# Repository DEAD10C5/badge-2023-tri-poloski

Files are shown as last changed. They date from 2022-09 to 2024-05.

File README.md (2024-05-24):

# взаимоблокировщики - гопник badge - Путин хуйло

 

## Created by

Будущее подпольной кибер-безопасности

- Concept: Yaya Pancho
- Translations: @muscovitebob
- Puzzle: [Hermit](mailto:hermit@dead10c5.org)
- Hardware: [p0lr](mailto:p0lr@dead10c5.org) [@thedevilsvoice](mailto:thedevilsvoice@dead10c5.org)
- Software: [p0lr](mailto:p0lr@dead10c5.org) [@thedevilsvoice](mailto:thedevilsvoice@dead10c5.org)

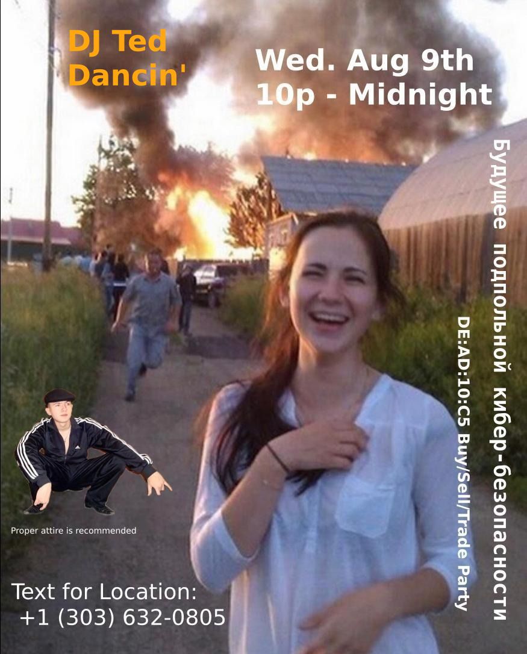
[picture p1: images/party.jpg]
party


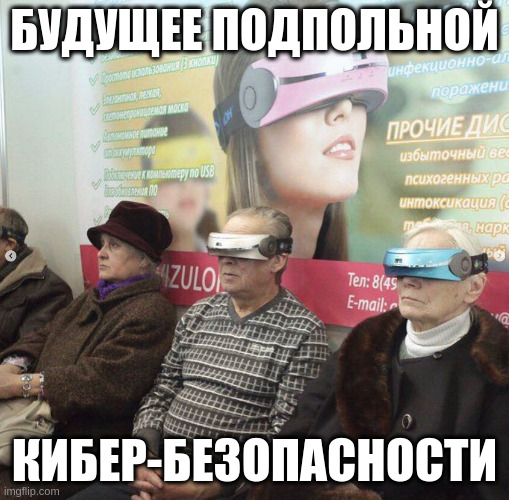
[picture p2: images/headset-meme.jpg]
headset
)

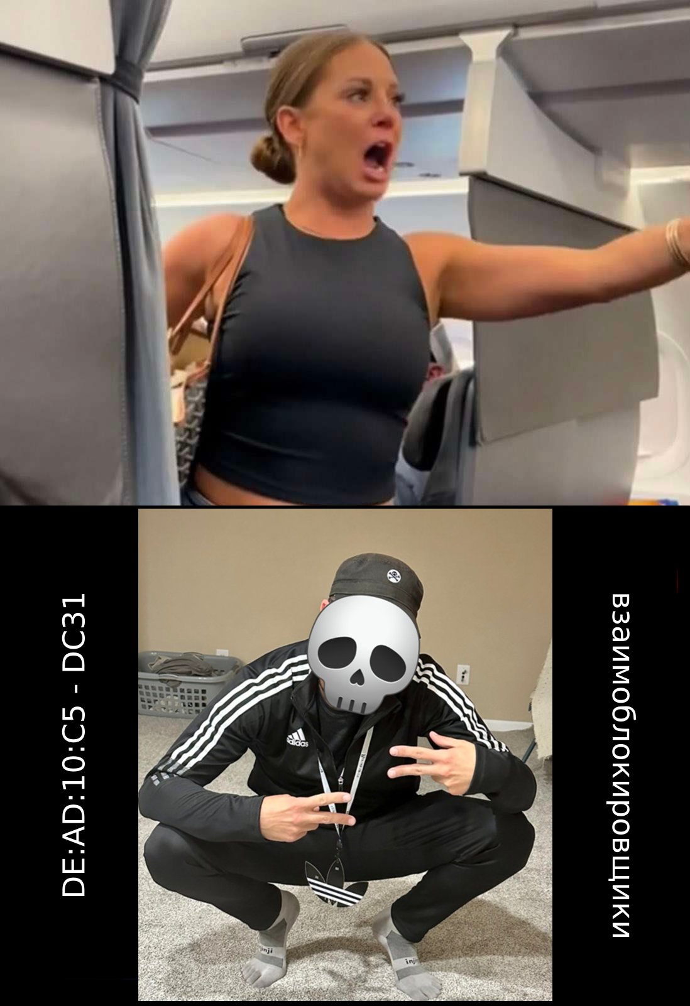
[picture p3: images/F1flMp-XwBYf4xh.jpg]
airplane


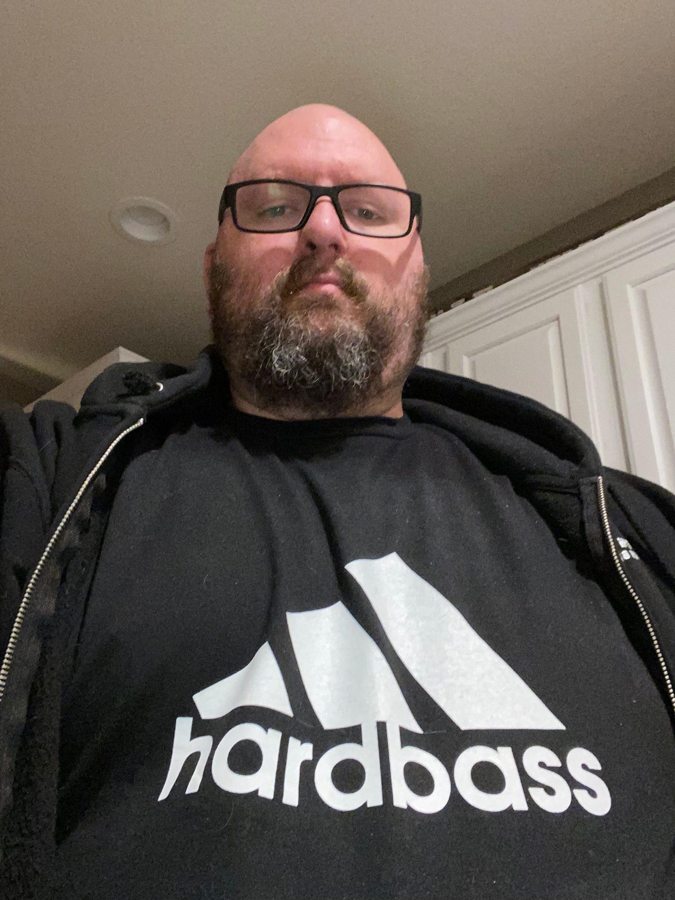
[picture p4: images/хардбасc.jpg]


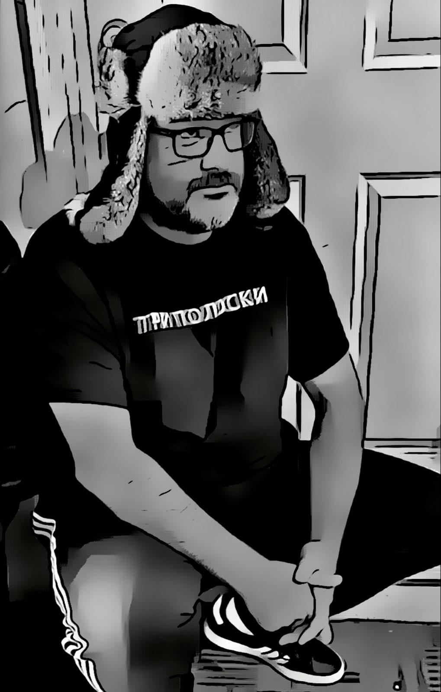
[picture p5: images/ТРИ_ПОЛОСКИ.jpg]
ТРИ-ПОЛОСКИ


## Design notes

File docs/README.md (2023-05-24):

# Docs go here

Generate the Gerbers like so:
`bash kicad-exports -c docs/gerbers.kibot.yaml -d docs -b kicad/adidas.kicad_pcb -e kicad/adidas.kicad_sch`

## Routing

1. From the main KiCAD window, select the "Plugin and Contect Manager"
2. Install the "Freerouting" plug in.
3. Install the "PCBWay plug in for KiCAD"

You can also use the older [FreeRouting](https://github.com/freerouting/freerouting) tool.

```sh
locate freeRouting.jar
java -jar /opt/layout/bin/freeRouting.jar
```

Board Settings

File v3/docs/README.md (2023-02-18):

# Docs go here

Generate the Gerbers like so:
`bash kicad-exports -c docs/gerbers.kibot.yaml -d docs -b kicad/adidas.kicad_pcb -e kicad/adidas.kicad_sch`

## Routing

[FreeRouting](https://github.com/freerouting/freerouting)

## Setup

- Install Arduino IDE.
- Click `file -> Preferences`
- Add this to `Additional Boards manager URLS`: `http://drazzy.com/package_drazzy.com_index.json`
- Click `ok`
- Click on `Tools -> Boards Manager` and make sure `ATTinyCore` is installed.
  - Install version 1.5.2 or later.
- Select one of the ATTiny 441/841 board types.

## Libraries

- [ATTinyCore Universal](https://github.com/SpenceKonde/ATTinyCore)
- [TinyMPU6050](https://github.com/gabriel-milan/TinyMPU6050)

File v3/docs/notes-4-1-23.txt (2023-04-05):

1. move the MPU or the battery so it is easier to insert the coin cell
2. The mounting hole is missing from the board. (1, 2, or 3 holes?)
3. Can the chip be programmed while it is attached to the board? Depends on connections?
4. the switch is not needed with "regular" LED. Could still be used for blink patterns?
5. Break out all the pins from the chip from now on. That way you can still prototype
   if there is some issue with the circuits. 

we can use the "optiboot" core and program the chip using USB to serial converter. 

## Burn Bootloader

- Use ARduino IDE 2.0.4 or later
- Add the "Arduino AVR Boards" from board manager.
- Upload the `src/ArduinoISP` sketch to the Arduino UNO.
- Connect board and "get board info", you should see serial number.

Pin details for ISP header:
// By default, the hardware SPI pins MISO, MOSI and SCK are used to communicate
// with the target. On all Arduinos, these pins can be found
// on the ICSP/SPI header:
//
//               MISO °. . 5V (!) Avoid this pin on Due, Zero...
//               SCK   . . MOSI
//                     . . GND
//
// On some Arduinos (Uno,...), pins MOSI, MISO and SCK are the same pins as
// digital pin 11, 12 and 13, respectively. That is why many tutorials instruct
// you to hook up the target to these pins. If you find this wiring more
// practical, have a define USE_OLD_STYLE_WIRING. This will work even when not
// using an Uno. (On an Uno this is not needed).

Choose Bootloader UART1 if you are using ISP header programming since the TX is on pin 8 and the RX is on pin 9.

const uint8_t  DATA_PIN   = PA5; // pin 8
const uint8_t  CLOCK_PIN  = PA4; // SCL pin 9

Choose board ATtiny441/841 with Optiboot. This allows programming via USB to Serial cable not just ISP header.
Programmer: ATtiny as ISP (ATtiny Core)

For USB to TTL, while viewing the BACK of the board:
- Green/Grey wire: TX out of the USB port, RX on the chip, connect to bottom center pin on ISP header next to green/grey.
- White wire: RX into USB port, TX on the chip, connect bottom left (below power).
- Black wire: Connect to negative (-) port on back, top right of ISP header.
- Red/Orange wire: Connect to (+) port on the back, top l;eft of ISP header.

Connect board, burn bootloader from board menu.
Then you can start uploading sketches

## Programming

Once you burn the bootloader to the chip, you can reflash many times using the easy USB to TTL cable.

[Add the ATTINY 841 using these directions](https://github.com/SpenceKonde/ATTinyCore/blob/v2.0.0-devThis-is-the-head-submit-PRs-against-this/Installation.md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)

[SparkFun FT231X Breakout](https://www.sparkfun.com/products/13263)

## Serial Console

pin13 SCK
pin12 MISO
pin11 MOSI
pin10 SS

You can make a serial connection to the badge using a USB to TTL serial cable.
For example: [USB to TTL Serial Cable](https://www.adafruit.com/product/954)

- Green wire: Connect to serial port, right side looking at back.
- White wire: Connect to serial port, left side looking at back.
- Black wire: Connect to Battery port, negative (-) port.
- Red/Orange wire: Do not connect! This is +5V but the board is at +3V.

TERM=linux minicom -D /dev/ttyUSB0 -b 9600

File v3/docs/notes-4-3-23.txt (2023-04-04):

## Soldering

- Solder a (B3F-1000 Omron Switch](https://omronfs.omron.com/en_US/ecb/products/pdf/en-b3f.pdf)
  to the back of the board in the bottom center. The button is used to toggle between
  light pattern modes.
- Solder a [Keystone SMT 3002 coin cell retainer](https://www.digikey.com/en/products/detail/keystone-electronics/3002/227444)
  to the back middle of the board.
- (OPTIONAL) solder a 2×3 Pin 6 Pin With Polarizing Key. The connector should be oriented as
  shown in the [AND!XOR SAO Reference Designs](https://github.com/DEAD10C5/badge-project-template/blob/main/docs/shitty_add_ons.md)

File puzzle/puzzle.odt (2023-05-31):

🍈🫒🫒🍈🫒,🍈🫒🍎🍈🍎,🍈🫒🍎🫒🍎,🍈🫒🍈🍎,🍎🍎🍎🍈,🍈🫒🍎🍎🍎,🍈🫒🍎🍈🍎,🍈🍈🫒🍎🫒,🍈🫒🍈🍎🍈,🍈🍈🫒🫒🍎,🍈🫒🍈🍎🍈,🍈🫒🍈🍎,🍈🫒🍈🍎🍈,🍈🍈🫒🍎🫒,🍈🫒🍎🫒🍎,🍈🫒🍈🍎,🍈🍈🫒🫒🍎,🍈🍈🫒🍈🫒,

🍈🍈🫒🍎🍎,🍈🫒🍈🍎,🍈🍈🫒🍎🍈,🍈🫒🍎🫒🍎,🍈🫒🍎🫒🍎,🍈🍈🫒🫒🍎,🍈🫒🍈🍎,🍈🫒🍈🍎🍎,🍈🍈🍈🫒🫒,🍈🍈🫒🍎🍎,🍈🫒🍈🍎,🍈🫒🍎🫒🍎,🍈🍈🍈🫒🍈,🍈🍈🫒🍈🫒,🍈🍈🫒🫒🫒,🍈🍈🍈🫒🍈,🍈🫒🍎🫒🍎,🍈🫒🍈🍎,

🍈🍈🫒🍎🍎,🍈🫒🍎🍈🍎,🍈🫒🍎🫒🍎,🍈🫒🍈🍎,🍈🫒🍎🍎🍎,🍈🫒🍎🫒🍎,🍈🍈🍈🍈🍈,🍈🫒🍈🍎,🍈🫒🫒🍈🫒,🍈🍈🫒🍈🫒,🍈🫒🍈🍎,🍈🫒🍈🍎🍈,🍈🍈🫒🍎🫒,🍈🍈🫒🍎🫒,🍈🫒🍎🍎🫒,🍈🍈🍈🫒🍈,🍈🫒🍎🫒🍎,🍈🫒🍈🍎,

🍈🫒🍈🍎🍈,🍈🍈🫒🍎🍎,🍈🫒🍈🍎,🍈🍈🫒🍎🍎,🍈🫒🍎🍈🍎,🍈🫒🍎🫒🍎,🍈🫒🍈🍎,🍈🫒🍎🫒🍎,🍈🍈🫒🫒🍎,🍈🫒🍎🫒🍈,🍈🫒🍈🍎,🍈🫒🍎🍈🫒,🍈🍈🫒🍈🫒,🍈🍈🫒🫒🫒,🍈🍈🫒🫒🫒,🍈🍈🫒🍈🫒,🍈🍈🍈🫒🍎,🍈🫒🍈🍎,

🍈🍈🫒🍎🍎,🍈🫒🍎🍈🍎,🍈🫒🍎🫒🍎,🍈🫒🍈🍎,🍈🫒🍎🍈🍎,🍈🫒🍎🍎🫒,🍈🍈🫒🍎🍈,🍈🍈🫒🍎🍎, 🍈🍈🫒🍈🫒,🍈🍈🫒🍎🫒,🍈🍈🍈🍈🍈

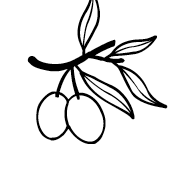
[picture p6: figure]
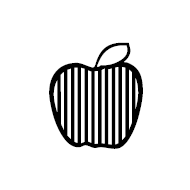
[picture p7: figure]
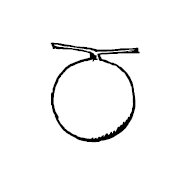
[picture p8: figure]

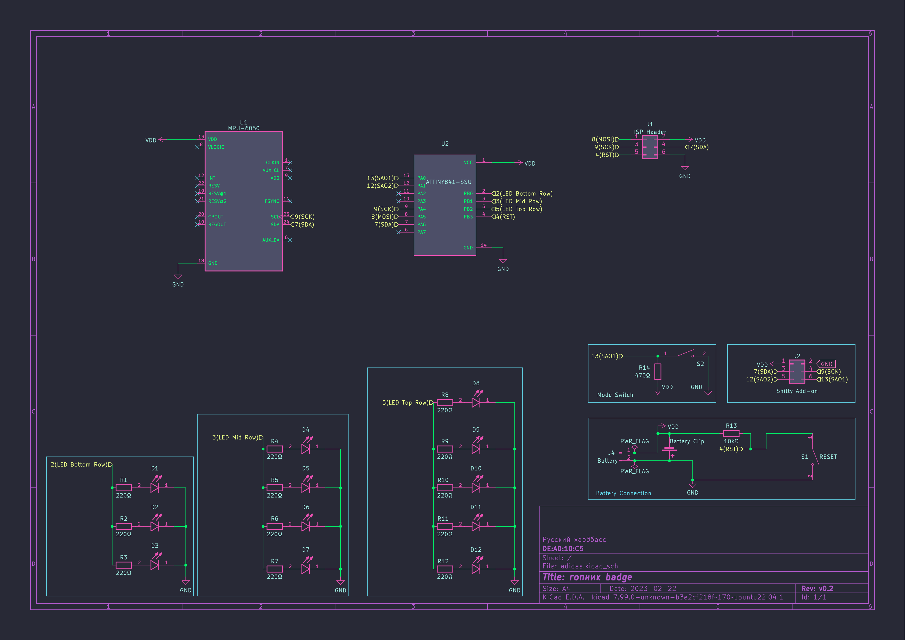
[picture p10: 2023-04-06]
images/schematic-v2.png

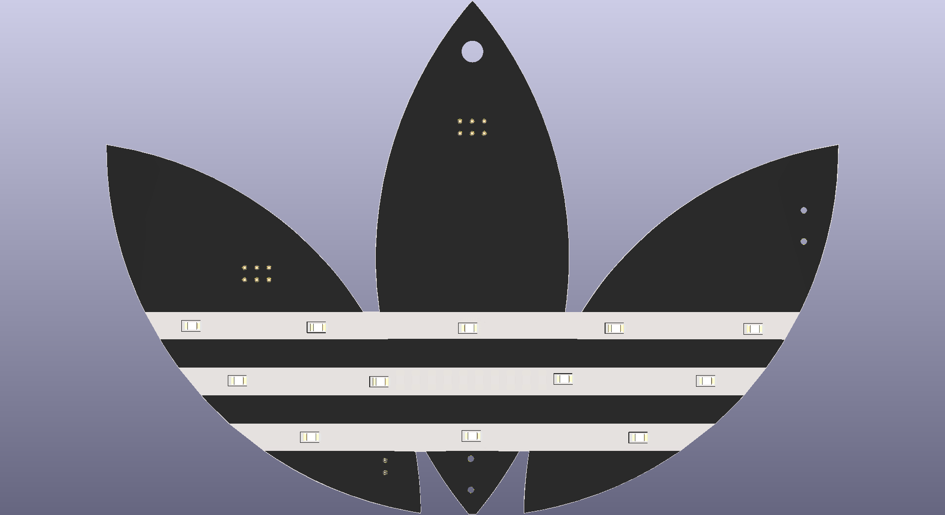
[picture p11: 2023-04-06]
images/adidas-front-3d-v2.png

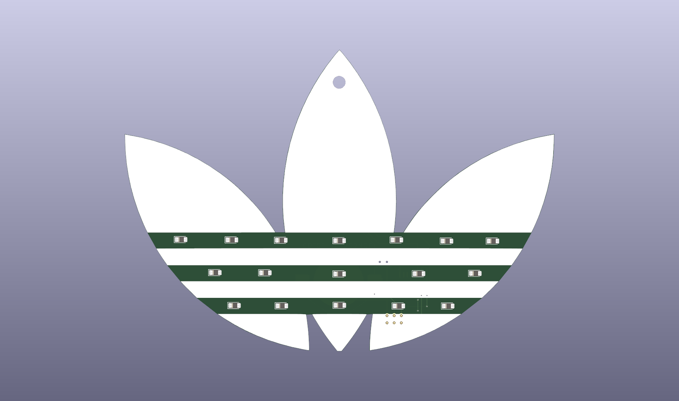
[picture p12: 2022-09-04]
images/adidas.png

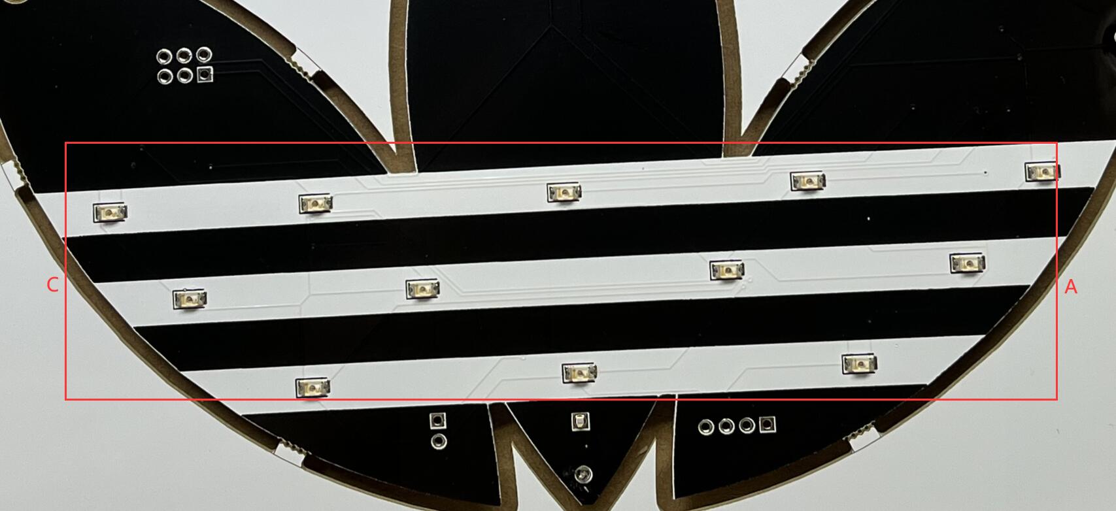
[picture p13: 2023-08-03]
images/LED orientation confirmtion.jpg

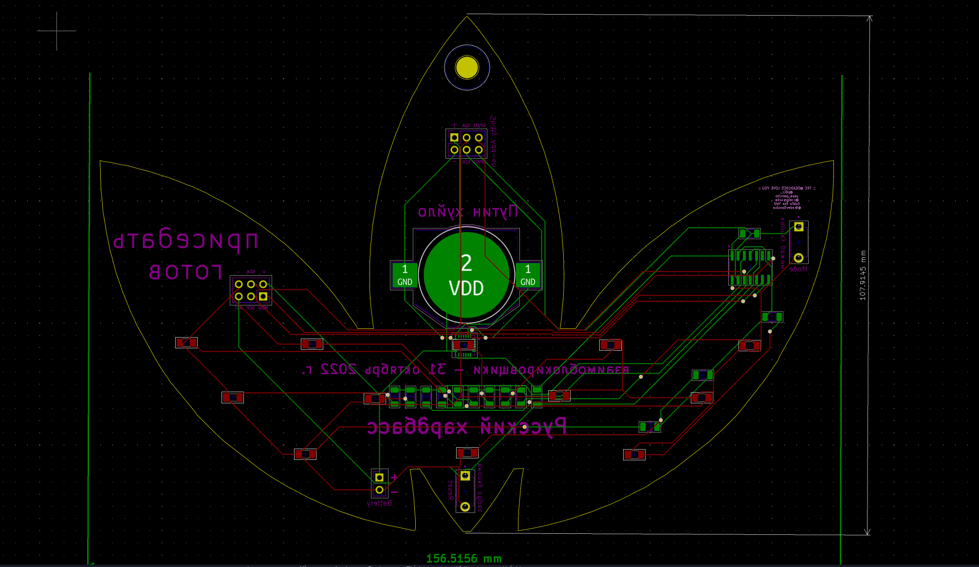
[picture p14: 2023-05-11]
images/almost_final1.png

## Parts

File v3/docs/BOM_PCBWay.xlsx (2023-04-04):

 |  |  | xxxx xxxx xxxxx xxPCS BOM (Sample Bill of Materials)
Item # | *Designator | *Qty | Manufacturer | *Mfg Part # | Description / Value | *Package/Footprint | Type | Your Instructions / Notes
1 | D2,D5,D12,D4,D6,D10,D8,D9,D11,D3,D7,D1 | 12 |  | LEDC3216X120N | LHN974 |  | SMD
2 | R3,R2,R1 | 3 |  | R_1206_3216Metric_Pad1.30x1.75mm_HandSolder | R |  | SMD
3 | J2 | 1 |  | TestPoint_2Pads_Pitch2.54mm_Drill0.8mm | Conn_01x02_Female |  | SMD
4 | BT1 | 1 |  | BatteryHolder_Keystone_3002_1x2032 | Battery_Cell |  | SMD
5 | U2 | 1 |  | SOIC127P599X175-14N | ATTINY841-SSU |  | SMD
8 | U1 | 1 |  | QFN50P400X400X95-24N | MPU-6050 |  | QFP
Need a quick and accurante quote? Need an efficient production? Please read SMT Ordering Necessary Files & Info in 1 minute. Thank you very much! (https://www.pcbway.com/smt_ordering_guide.html)
Click for Instructions on How to Create a BOM (https://www.pcbway.com/blog/PCB_Assembly/How_to_Build_a_BOM__Bill_Of_Materials_.html)

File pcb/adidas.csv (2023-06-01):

Source: | /Users/fdiaz/workspace/badge-2023-tri-poloski/pcb/adidas.kicad_sch
Date: | 2023 June 01, Thursday 18:16:46
Tool: | Eeschema 7.99.0-1211-g2ac3f4cc9e
Generator: | /Applications/KiCad/KiCad.app/Contents/SharedSupport/plugins/bom_csv_grouped_by_value.py
Component Count: | 31
Collated Components:
Item | Qty | Reference(s) | Value | LibPart | Footprint | Datasheet | DNP | 1 | 2 | 3 | 4 | A1_MIN | AVAILABILITY | A_MAX | A_MIN | A_NOM | B_MAX | B_MIN | B_NOM | D2_MAX | DESCRIPTION | D_MAX | D_MIN | D_NOM | Description | Digi-Key Part Number | Digikey | E1_MAX | E1_MIN | E1_NOM | E2_MAX | ENOM | E_MAX | E_MIN | E_NOM | L_MAX | L_MIN | L_NOM | MANUFACTURER | MAXIMUM_PACKAGE_HEIGHT | MF | MP | Manufacturer | Manufacturer Part Num | Manufacturer Product Number | Mouser Part | PACKAGE | PARTREV | PIN_COUNT | PRICE | Part | SNAPEDA_PN | STANDARD | name | purpose
1 | 12 | D1, D2, D3, D4, D5, D6, D7, D8, D9, D10, D11, D12 | SM1206NHC-IL | dead10c5:LED-SMD-0805 | LED_SMD:LED_1206_3216Metric | https://www.bivar.com/parts_content/Datasheets/SM1206NHC-IL.pdf |  |  |  |  |  |  |  |  |  |  |  |  |  |  |  |  |  |  |  | 492-1944-1-ND |  |  |  |  |  |  |  |  |  |  |  |  | Bivar |  |  |  |  |  | SM1206NHC-IL
2 | 1 | J3 | Conn_01x04_Pin | Connector:Conn_01x04_Pin | Connector_PinHeader_2.54mm:PinHeader_1x04_P2.54mm_Vertical | ~ |  | RED | GREEN | WHITE | BLACK |  |  |  |  |  |  |  |  |  |  |  |  |  |  |  |  |  |  |  |  |  |  |  |  |  |  |  |  |  |  |  |  |  |  |  |  |  |  |  |  |  |  | Serial header
3 | 12 | R1, R2, R3, R4, R5, R6, R7, R8, R9, R10, R11, R12 | 220Ω | Device:R | Resistor_SMD:R_1206_3216Metric | https://www.yageo.com/upload/media/product/productsearch/datasheet/rchip/PYu-RC_Group_51_RoHS_L_12.pdf |  |  |  |  |  |  |  |  |  |  |  |  |  |  |  |  |  |  |  |  | https://www.digikey.com/en/products/detail/yageo/RC1206JR-07220RL/729251 |  |  |  |  |  |  |  |  |  |  |  |  |  |  |  | YAGEO |  | RC1206JR-07220RL |  |  |  |  |  | RC1206JR-07220RL
4 | 1 | R13 | 10kΩ | Device:R | Resistor_SMD:R_1206_3216Metric | https://www.yageo.com/upload/media/product/productsearch/datasheet/rchip/PYu-RC_Group_51_RoHS_L_12.pdf |  |  |  |  |  |  |  |  |  |  |  |  |  |  |  |  |  |  | RES 10K OHM 5% 1/4W 1206 | 311-10KERCT-ND |  |  |  |  |  |  |  |  |  |  |  |  |  |  |  |  | YAGEO |  | RC1206JR-0710KL
5 | 1 | R14 | 470Ω | Device:R | Resistor_SMD:R_1206_3216Metric | ~
6 | 2 | S1, S2 | TL1107BF180WQ | dead10c5:TL1107BF130WQ | DEAD10C5:SW_TL1107BF130WQ | https://eswitch.wpengine.com/wp-content/uploads/2022/06/TL1107.pdf |  |  |  |  |  |  |  |  |  |  |  |  |  |  |  |  |  |  |  | EG2513-ND |  |  |  |  |  |  |  |  |  |  |  |  | E-Switch | 4.3mm |  |  | E-Switch | TL1107BF180WQ |  |  |  | - |  |  |  | TL1107BF180WQ | Manufacturer Recommendations |  | RESET
7 | 1 | U1 | MPU-6050 | dead10c5:MPU-6050 | DEAD10C5:QFN50P400X400X95-24N | https://product.tdk.com/system/files/dam/doc/product/sensor/mortion-inertial/imu/data_sheet/mpu-6000-datasheet1.pdf |  |  |  |  |  |  | Good |  |  |  |  |  |  |  | IMU ACCEL/GYRO 3-AXIS I2C 24QFN |  |  |  | IMU ACCEL/GYRO 3-AXIS I2C 24QFN |  |  |  |  |  |  |  |  |  |  |  |  |  |  |  | TDK | MPU-6050 | TDK |  | MPU-6050 | 410-MPU-6050 | QFN-24 InvenSense | 3.4 |  | 5.45 USD |  |  | IPC-7351B
8 | 1 | U2 | ATTINY841-SSU | dead10c5:ATTINY841-SSU | DEAD10C5:SOIC127P599X175-14N | https://www.mouser.com/datasheet/2/268/Atmel_8495_8_bit_AVR_Microcontrollers_ATtiny441_AT-1315526.pdf |  |  |  |  |  | 0.1 |  | 1.75 | 1.75 | 1.75 | 0.5 | 0.33 | 0.415 | 0.0 |  | 8.74 | 8.55 | 8.645 |  |  |  | 3.99 | 3.8 | 3.895 | 0.0 | 1.27 | 6.19 | 5.8 | 5.995 | 1.27 | 0.41 | 0.84 | Microchip | 1.75mm |  |  |  |  |  |  |  | A | 14.0 |  |  |  | IPC 7351B

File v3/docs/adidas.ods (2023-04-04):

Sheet: dev kit
PART | DESCRIPTION | LINK
USB to TTL Serial Cable] | Use this cable and maybe a few jumper wires along with the small test clips to flash and communicate over serial. | https://www.adafruit.com/product/954
SDK08 Test Clip Ultra Small Clip | Use three of these small clips to connect to ground, RX and TX for programming and serial console. They are super fragile so buy a few extras. The connection directions are here: https://github.com/DEAD10C5/badge-2023-tri-poloski/blob/main/test/hardware_test/README.md | https://www.amazon.com/KESOTO-SDK08-Ultra-Small-Adapters/dp/B095Y39DWC
2×3 Pin 6 Pin With Polarizing Key | Use one of these at the top of the board to connect a shitty add on. The full directions for SAO are here: https://github.com/DEAD10C5/badge-project-template/blob/main/pcb/docs/shitty_add_ons.md | https://www.ebay.com/itm/173960769032

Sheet: adidas
Component Count: | 27
Item | Qty | Reference(s) | Value | Digi-Key Part Number | Manufacturer | Manufacturer Product Number | Mouser Part | Datasheet
1 | 12 | D1, D2, D3, D4, D5, D6, D7, D8, D9, D10, D11, D12 | CTL1206FWH1T | 2679-CTL1206FWH1TTR-ND | Venkel | CTL1206FWH1T |  | https://page.venkel.com/hubfs/Resources/Datasheets/LEDs/CTL1206FWH1T.pdf
2 | 12 | R1, R2, R3, R4, R5, R6, R7, R8, R9, R10, R11, R12 | 220Ω | 311-220ERCT-ND | YAGEO | RC1206JR-07220RL |  | https://www.yageo.com/upload/media/product/productsearch/datasheet/rchip/PYu-RC_Group_51_RoHS_L_12.pdf
3 | 1 | R13 | 10kΩ | 311-10KERCT-ND | YAGEO | RC1206JR-0710KL |  | https://www.yageo.com/upload/media/product/productsearch/datasheet/rchip/PYu-RC_Group_51_RoHS_L_12.pdf
4 | 1 | U1 | MPU-6050 |  | TDK | MPU-6050 | 410-MPU-6050 | https://product.tdk.com/system/files/dam/doc/product/sensor/mortion-inertial/imu/data_sheet/mpu-6000-datasheet1.pdf
5 | 1 | U2 | ATTINY841-SSU | ATTINY841-SSU-ND | Microchip | 556-ATTINY841-SSU |  | https://www.mouser.com/datasheet/2/268/Atmel_8495_8_bit_AVR_Microcontrollers_ATtiny441_AT-1315526.pdf

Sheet: wiring
header pin | chip pin | desc of serial interface | port pin
1 | pin8 | MISO | PA5
2 |  | power
3 | pin9 | SCL, SCK | PA4
4 | pin7 | SDA, MOSI | PA6
5 | pin4 | RST (NC?) | PB3
6 |  | GND

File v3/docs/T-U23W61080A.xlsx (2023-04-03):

T-U23W61080A-BOM
No. Item | 型号 Mfg Part | 封装 Package/Footprint | 规格参数 Description / Value | 位号 Designator | 单板用量 Qty per board | 物料备注 Instructions / Notes | 不良原因 Assembly Question | 客户回复 Reply from Customer
1 | SM1206NHC-IL | LED_SMD:LED_1206_3216Metric | CTL1206FWH1T | D1,D2,D3,D4,D5,D6,D7,D8,D9,D10,D11,D12 | 12 | SM1206NHC-IL | We purchased RED LEDs according to part number, but no color is listed in BOM, is it OK to be used ?
4 | MPU-6050 | DEAD10C5:QFN50P400X400X95-24N | MPU-6050 | U1 | 1 | sensitive led | There's no correponding solder pad at the center of the U1 pads, pls advise how should we proceed.

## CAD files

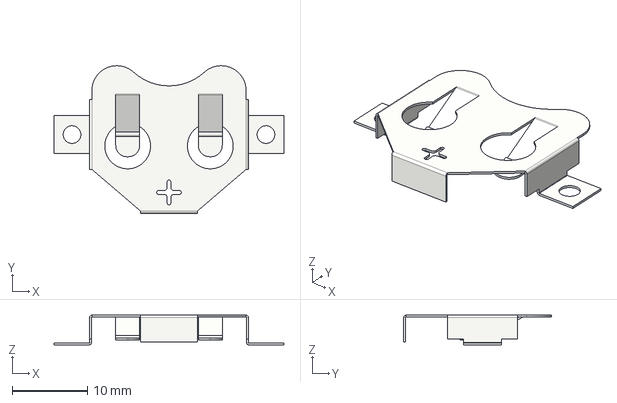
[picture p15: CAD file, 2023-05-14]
pcb/3d/battery_clip.step
30.7 x 19.7 x 3.96 mm

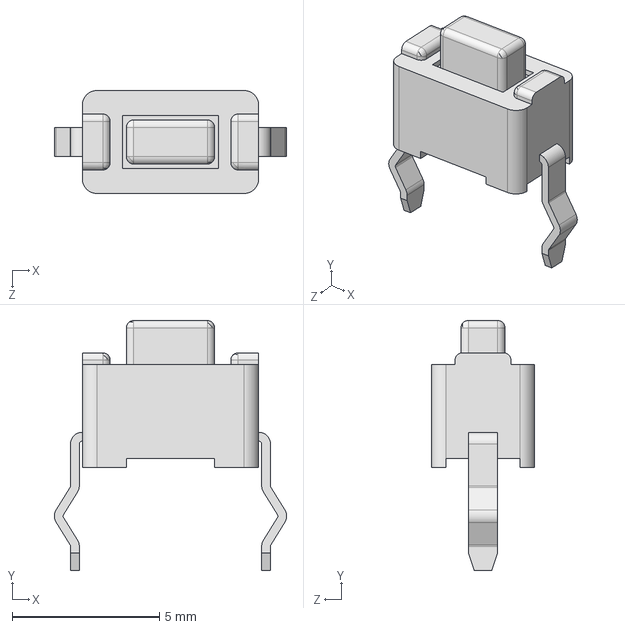
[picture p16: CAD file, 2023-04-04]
v3/3d/TL1107BF130WQ.step
7.90 x 8.50 x 3.50 mm

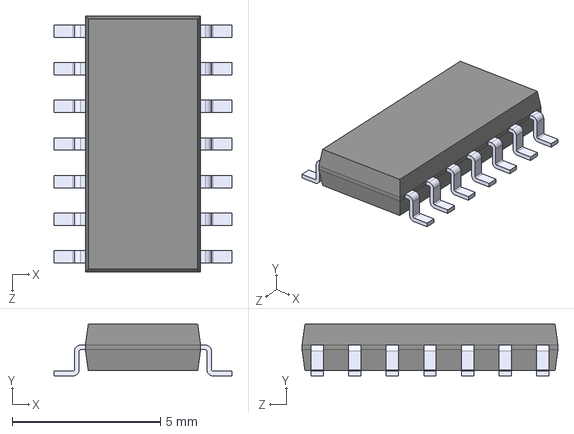
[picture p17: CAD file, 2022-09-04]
v3/3d/ATTINY841-SSU.step
5.99 x 1.75 x 8.65 mm

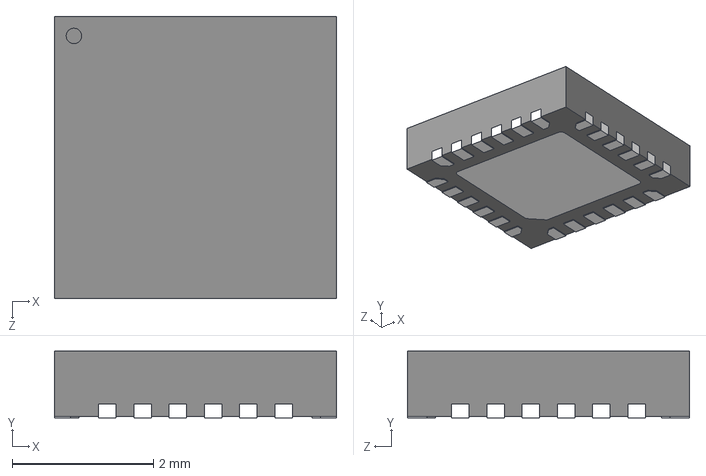
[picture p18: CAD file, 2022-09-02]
v3/3d/MPU-6050.step
4.00 x 0.95 x 4.00 mm

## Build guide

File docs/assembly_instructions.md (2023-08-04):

# Assembly

## Parts

- 2 switches (need to order 400)
- battery clips
- batteries
- SAO headers

## Assembly Steps

- Solder a [Keystone SMT 3002 coin cell retainer](https://www.digikey.com/en/products/detail/keystone-electronics/3002/227444)
  to the back middle of the board.
- (OPTIONAL) solder a 2×3 Pin 6 Pin With Polarizing Key. The connector should be oriented as shown in the
  [AND!XOR SAO Reference Designs](https://github.com/DEAD10C5/badge-project-template/blob/main/docs/shitty_add_ons.md)

## Flashing

- [SparkFun AVR Pocket Programmer](https://learn.sparkfun.com/tutorials/pocket-avr-programmer-hookup-guide/all)
- Set "Tools -> Programmer" to "USBtinyASP (FAST)"
- Means you don't need a boot loader. Saves some memory.

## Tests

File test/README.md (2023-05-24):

# Test

## Chip Setup

Configure the Arduino IDE for use with the ATTiny841 chip.

- Install Arduino IDE.
- Click `file -> Preferences` (on MacOS `Arduino IDE -> Settings`)
- Add this to `Additional Boards manager URLS`:
  `http://drazzy.com/package_drazzy.com_index.json`
- Click `ok`
- Click on `Tools -> Boards Manager` (on MacOS `Tools -> Board -> Boards Manager`) and make sure
  `ATTinyCore` is installed.
  - Install version 1.5.2 or later.
- Click on `Tools -> Board -> ATTinyCore` and select one of the ATTiny 441/841 board types.
- Click on `File -> Open` and select the `test/accelerometer_test.ino file` in this repo
- A dialog appears asking if you want to create a folder and move the file, press `OK`
- Click on `Sketch -> Include Library -> Manage Libraries`. In the search bar, type "TinyMPU6050"
  and click the `INSTALL` button
- Start a build by pressing the button with the checkmark in the upper left of the window

### Install Libraries

These libraries extend the Arduino environment with extra functions
related to our specific hardware.

- Save these zip files to the `Arduino/libraries` folder.
  - In your home directory if using Linux.
- Unzip them.
- You might need to restart KiCAD.

- [ATTinyCore Universal](https://github.com/SpenceKonde/ATTinyCore)
- [TinyMPU6050](https://github.com/gabriel-milan/TinyMPU6050)

## Burn Bootloader (OPTIONAL)

This is a "factory only" step. By the time you get a dev kit,
this should have been completed already.

- Use Arduino IDE 2.0.4 or later
- Add the "Arduino AVR Boards" from board manager.
- Upload the `src/ArduinoISP` sketch to the Arduino UNO.
- Connect board and "get board info", you should see serial number.

Choose Bootloader UART1 if you are using ISP header programming since the
`TX` is on pin 8 and the `RX` is on pin 9.

```C
const uint8_t  DATA_PIN   = PA5; // pin 8
const uint8_t  CLOCK_PIN  = PA4; // SCL pin 9
```

Choose board ATtiny441/841 with Optiboot. This allows programming
via USB to Serial cable not just ISP header.

- Programmer: ATtiny as ISP (ATtiny Core)

For USB to TTL, while viewing the BACK of the board:

- Green/Grey wire: TX out of the USB port, RX on the chip, connect to
  bottom center pin on ISP header next to green/grey.
- White wire: RX into USB port, TX on the chip, connect bottom left (below power).
- Black wire: Connect to negative (-) port on back, top right of ISP header.
- Red/Orange wire: Connect to (+) port on the back, top l;eft of ISP header.

Connect board, burn bootloader from board menu.

Then you can start uploading sketches as show in the next section.

## Flashing

Each time you make changes to your code that you want to test, you will
flash the board with your latest udates.

Connect the cable to the board like so:

- Green wire: Connect to serial port, white TX pin 8
- White wire: Connect to serial port, green RX pin 9
- Black wire: Connect to Battery pin1, negative (-) port.
- Red/Orange wire: pin14 (+)

## Serial Console

You can make a serial connection to the badge using a USB to TTL serial cable.
For example: [USB to TTL Serial Cable](https://www.adafruit.com/product/954)

- Green wire: Connect to serial port, white SCL pin 12
- White wire: Connect to serial port, green SCK pin 9
- Black wire: Connect to Battery, negative (-) pin1
- Red/Orange wire: Battery, positive (+) pin14

You can use `minicom` outside the Arduino IDE to make serial connections if needed.

```sh
TERM=linux minicom -D /dev/ttyUSB0
```

## PlatformIO

This directory is intended for PlatformIO Unit Testing and project tests.

Unit Testing is a software testing method by which individual units of
source code, sets of one or more MCU program modules together with associated
control data, usage procedures, and operating procedures, are tested to
determine whether they are fit for use. Unit testing finds problems early
in the development cycle.

- [More information about PlatformIO Unit Testing](https://docs.platformio.org/page/plus/unit-testing.html)

```sh
platformio pkg install -l ArduinoNative
platformio pkg install -l TinyWireM
```

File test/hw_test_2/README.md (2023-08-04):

# HW test 2

- trying out a smaller serial library [ATtinySerialOut](https://github.com/ArminJo/ATtinySerialOut)
- Testing with `wire` only, no dedicated library for MPU6050.
- We used generative AI to come up with this code

```sh
sudo apt install cpplint doxygen -y
sudo avrdude -c usbtiny -p t841 -U flash:w:/tmp/arduino_build_826069/gopnik.ino.hex
```

## Serial Console

You can make a serial connection to the badge using a USB to TTL serial cable.
For example: [USB to TTL Serial Cable](https://www.adafruit.com/product/954)

- Green wire: Connect to serial port, white SCL pin 12
- White wire: Connect to serial port, green SCK pin 9
- Black wire: Connect to Battery, negative (-) pin1
- Red/Orange wire: Battery, positive (+) pin14

You can use `minicom` outside the Arduino IDE to make serial connections if needed.

```sh
TERM=linux minicom -D /dev/ttyUSB0
```

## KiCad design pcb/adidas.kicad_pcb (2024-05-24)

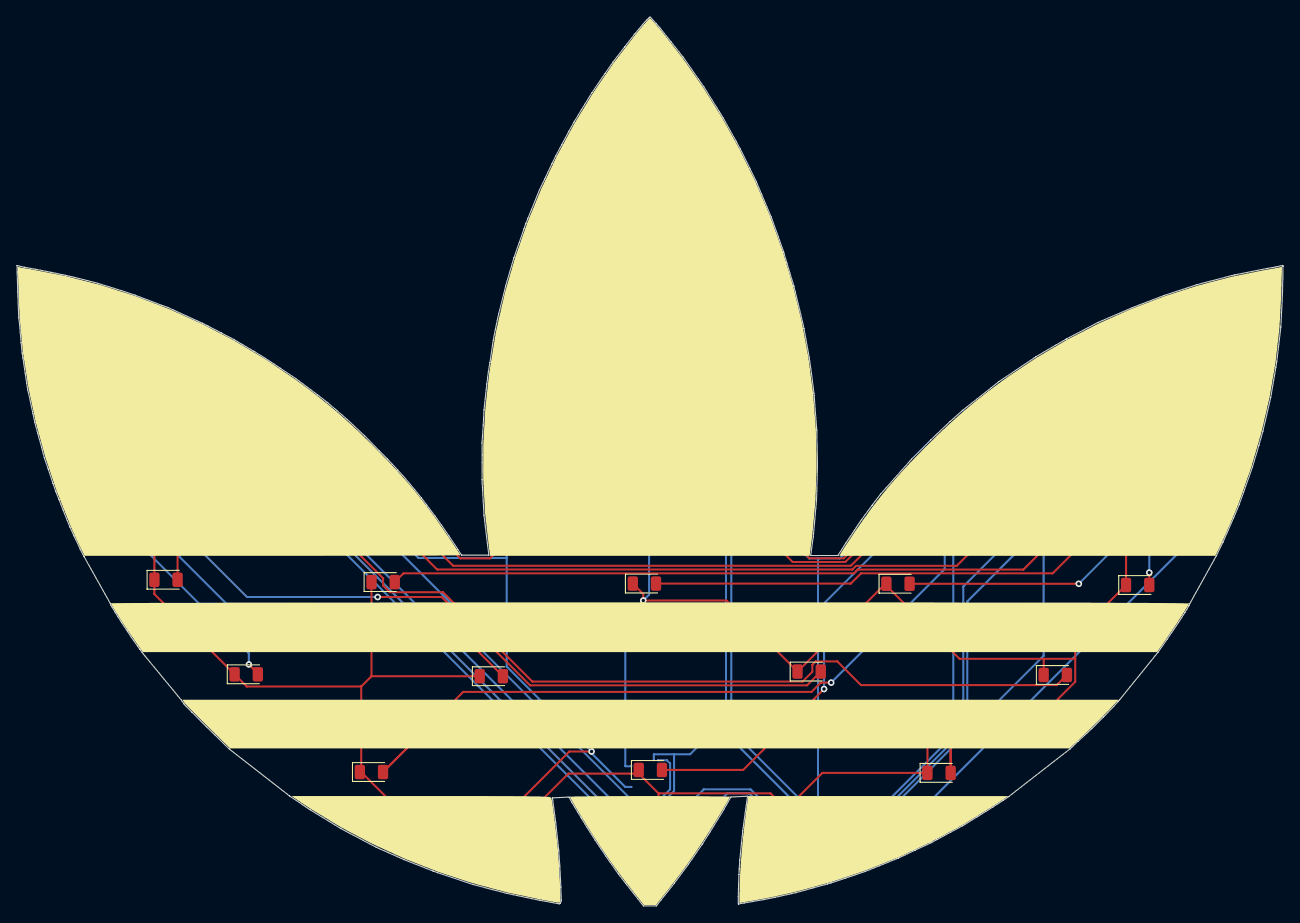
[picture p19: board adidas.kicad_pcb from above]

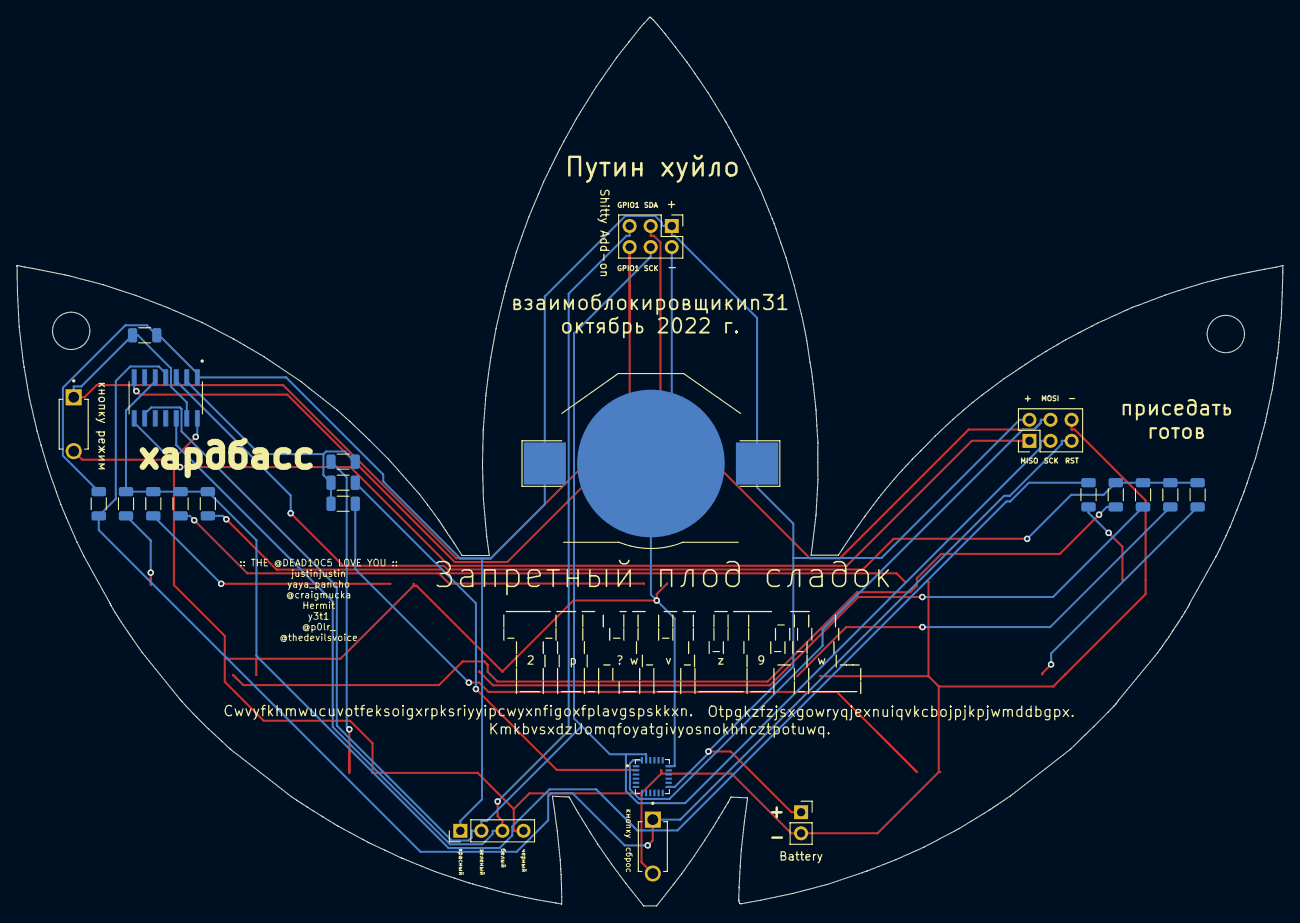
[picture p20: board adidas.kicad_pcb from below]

Board: 2 copper layers, 152.7 x 107.2 mm, 38 parts (23 on the bottom side), 23 nets.

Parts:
BT1: монетная батарейка; BatteryHolder_Keystone_3002_1x2032
D1, D2, D3, D4, D5, D6, D7, D8, D9, D10, D11, D12: SM1206NHC-IL; LED_1206_3216Metric
J1: ISP Header; PinHeader_2x03_P2.54mm_Vertical
J2: Shitty Add-on; PinHeader_2x03_P2.54mm_Vertical
J3: Conn_01x04_Pin; PinHeader_1x04_P2.54mm_Vertical
J4: Battery; PinSocket_1x02_P2.54mm_Vertical
R1, R2, R3, R4, R5, R6, R7, R8, R9, R10, R11, R12: 220Ω; R_1206_3216Metric
R13: 10kΩ; R_1206_3216Metric
R14: 470Ω; R_1206_3216Metric
S1, S2: TL1107BF180WQ; SW_TL1107BF130WQ
U1: MPU-6050; QFN50P400X400X95-24N
U2: ATTINY841-SSU; SOIC127P599X175-14N
hole1, hole2: MountingHole_4.5mm
silkscreen: LOGO; Adidas_Logo

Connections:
/2(LED Bottom Row): R1.1, R2.1, R3.1, U2.2 (PB0)
/3(LED Mid Row): R4.1, R5.1, R6.1, R7.1, U2.3 (PB1)
/4(RST): J1.5, R13.2, S1.1, U2.4 (PB3)
/5(LED Top Row): R8.1, R9.1, R10.1, R11.1, R12.1, U2.5 (PB2)
/7(SDA/MOSI): J1.4, J2.3, U1.24 (SDA), U2.7 (PA6)
/8(MISO): J1.1, U2.8 (PA5)
/9(SCK): J1.3, J2.4, J3.2, U1.23 (SCL), U2.9 (PA4)
/12(SAO2): J2.5, J3.3, U2.12 (PA1)
/13(SAO1): J2.6, R14.1, S2.1, U2.13 (PA0)
GND: BT1.2 (-), D1.1, D2.1, D3.1, D4.1, D5.1, D6.1, D7.1, D8.1, D9.1, D10.1, D11.1, D12.1, J1.6, J2.2, J3.4, J4.2, S1.2, S2.2, U1.18 (GND), U2.14 (GND)
unnamed: D1.2, R1.2
unnamed: D2.2, R2.2
unnamed: D3.2, R3.2
unnamed: D4.2, R4.2
unnamed: D5.2, R5.2
unnamed: D6.2, R6.2
unnamed: D7.2, R7.2
unnamed: D8.2, R8.2
unnamed: D9.2, R9.2
unnamed: D10.2, R10.2
unnamed: D11.2, R11.2
unnamed: D12.2, R12.2
VDD: BT1.1 (+), J1.2, J2.1, J3.1, J4.1, R13.1, R14.2, U1.13 (VDD), U2.1 (VCC)

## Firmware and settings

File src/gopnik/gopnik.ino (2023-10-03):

/*!
   @file gopnik.ino
    ____  _____      _    ____    _  ___     ____ ____
   |  _ \| ____|_   / \  |  _ \ _/ |/ _ \ _ / ___| ___|
   | | | |  _| (_) / _ \ | | | (_) | | | (_) |   |___ \
   | |_| | |___ _ / ___ \| |_| |_| | |_| |_| |___ ___) |
   |____/|_____(_)_/   \_\____/(_)_|\___/(_)\____|____/

  # SPDX-FileCopyrightText: 2023 DE:AD:10:C5 <polr@dead10c5.org>
  #
  # SPDX-License-Identifier: GPL-3.0-or-later
  Date   : August 02, 2023
  Version: 0.2

*/

#include "dead10c5.h"

void setup()
{
  Wire.begin();
  // Wire.setClock(400000L); //increase I2C speed to 400 khz 
  Wire.beginTransmission(MPU6050_ADDR);
  Wire.write(0x6B);           // Talk to the register 6B
  Wire.write(0);              // Make reset - place a 0 into the 6B register
  Wire.endTransmission(true); // end the transmission
  // Wire.beginTransmission(MPU6050_ADDR);
  // Wire.write(0x19);           // SMPLRT register
  // Wire.write(0);              // 1khz data rate
  // Wire.endTransmission(true); // end the transmission

  // LED Pins
  pinMode(LED_BOTTOM, OUTPUT);
  pinMode(LED_MIDDLE, OUTPUT);
  pinMode(LED_TOP, OUTPUT);

  // Button Pin
  pinMode(BUTTON, INPUT);

  // Set up the interrupt
  cli();
  PCMSK0 |= (1 << PCINT0);
  GIMSK |= (1 << PCIE0);
  sei();

  // Flash the lights so we know setup is done
  lights(1, 1, 1);
  delay(3);
  lights(0, 0, 0);
}

void accelerometer()
{
  int del = 20;
  Wire.beginTransmission(MPU6050_ADDR);
  Wire.write(0x3D); //changed to 3D to read y --> old // Wire.write(0x3B);
  Wire.endTransmission(false);
  Wire.requestFrom(MPU6050_ADDR, 2, true); //was 6
  // Wire.read()<<8|Wire.read(); //read X into _
  // AccelX = (Wire.read() << 8 | Wire.read()) / 16384.0; // X-axis value
  // AccelX = Wire.read() << 8 | Wire.read();
  // AccelY = (Wire.read() << 8 | Wire.read()) / 16384.0; // Y-axis value
  // AccelY = Wire.read() << 8 | Wire.read();
  accelYraw = Wire.read()<<8|Wire.read();
  __INT16_TYPE__ secondYraw = Wire.read()<<8|Wire.read();
  __INT16_TYPE__ dif = accelYraw - secondYraw;

  Wire.beginTransmission(MPU6050_ADDR);
  Wire.write(0x3D); //changed to 3D to read y --> old // Wire.write(0x3B);
  Wire.endTransmission(false);
  Wire.requestFrom(MPU6050_ADDR, 2, true); //was 6
  // Wire.read()<<8|Wire.read(); //read X into _
  // AccelX = (Wire.read() << 8 | Wire.read()) / 16384.0; // X-axis value
  // AccelX = Wire.read() << 8 | Wire.read();
  // AccelY = (Wire.read() << 8 | Wire.read()) / 16384.0; // Y-axis value
  // AccelY = Wire.read() << 8 | Wire.read();
  accelYraw = Wire.read()<<8|Wire.read();
  // AccelY = (float) accelYraw / 16384.0;
  // Wire.read()<<8|Wire.read();
  // Wire.read()<<8|Wire.read();
  // Wire.read()<<8|Wire.read();
  // Wire.read()<<8|Wire.read();
  // Wire.read()<<8|Wire.read(); //read the rest into _ to see if this flushes the buffer since its 14 wide
  if (accelYraw && 1){
    bot = true;
    mid = false;
    top = false;
  } else if (accelYraw && 3){
    bot = false;
    mid = false;
    top = true;
  } else {
    bot = false;
    mid = true;
    top = false;
  }
  lights(bot,mid,top);
  // delay(del);
  // AccelZ = (Wire.read() << 8 | Wire.read()) / 16384.0; // Z-axis value
  // AccelZ = Wire.read() << 8 | Wire.read();

  // Temp = Wire.read() << 8 | Wire.read(); // 0x41 (TEMP_OUT_H) & 0x42 (TEMP_OUT_L)

  //GyroX = Wire.read() << 8 | Wire.read(); // 0x43 (GYRO_XOUT_H) & 0x44 (GYRO_XOUT_L)
  //GyroY = Wire.read() << 8 | Wire.read(); // 0x45 (GYRO_YOUT_H) & 0x46 (GYRO_YOUT_L)
  //GyroZ = Wire.read() << 8 | Wire.read(); // 0x47 (GYRO_ZOUT_H) & 0x48 (GYRO_ZOUT_L)

  // Serial.print(Tmp/340.00+36.53);  //equation for temperature in degrees C from datasheet
}

void lights(bool b, bool m, bool t)
{
  digitalWrite(LED_BOTTOM, b);
  digitalWrite(LED_MIDDLE, m);
  digitalWrite(LED_TOP, t);
}

/* watching this interrupt to change mode if they are
moving the badge around the space time contiuum */
ISR(PCINT0_vect)
{
  if (digitalRead(BUTTON) == LOW)
  {
    set_mode();
  }
}

void set_mode()
{
  mode = mode + 1;
  if (mode > 5)
  {
    mode = 0;
  }
}

void rollup()
{
  int del = 20;
  lights(1, 0, 0);
  delay(del);
  lights(0, 1, 0);
  delay(del);
  lights(0, 0, 1);
  delay(del);
  lights(0, 0, 0);
}

void rolldown()
{
  int del = 20;
  lights(0, 0, 1);
  delay(del);
  lights(0, 1, 0);
  delay(del);
  lights(1, 0, 0);
  delay(del);
  lights(0, 0, 0);
}

void flash()
{
  int del = 10;
  lights(1, 1, 1);
  delay(del);
  lights(0, 0, 0);
  delay(del);
}

void flashyrollup()
{
  int del = 10;
  for (int counter = 0; counter < 4; counter++)
  {
    lights(1, 0, 0);
    delay(del);
    lights(0, 0, 0);
    delay(del);
  }
  for (int counter = 0; counter < 4; counter++)
  {
    lights(0, 1, 0);
    delay(del);
    lights(0, 0, 0);
    delay(del);
  }
  for (int counter = 0; counter < 4; counter++)
  {
    lights(0, 0, 1);
    delay(del);
    lights(0, 0, 0);
    delay(del);
  }
}

void flashyrolldown()
{
  int del = 10;
  for (int counter = 0; counter < 4; counter++)
  {
    lights(0, 0, 1);
    delay(del);
    lights(0, 0, 0);
    delay(del);
  }
  for (int counter = 0; counter < 4; counter++)
  {
    lights(0, 1, 0);
    delay(del);
    lights(0, 0, 0);
    delay(del);
  }
  for (int counter = 0; counter < 4; counter++)
  {
    lights(1, 0, 0);
    delay(del);
    lights(0, 0, 0);
    delay(del);
  }
}

void alternate()
{
  int del = 30;
  lights(1, 0, 1);
  delay(del);
  lights(0, 1, 0);
  delay(del);
}

void loop()
{

  // this is the default mode
  if (mode == 0)
  {
    rollup();
  }
  else if (mode == 1)
  {
    rolldown();
  }
  else if (mode == 2)
  {
    flash();
  }
  else if (mode == 3)
  {
    flashyrollup();
  }
  else if (mode == 4)
  {
    flashyrolldown();
  }
  else if (mode == 5)
  {
    alternate();
  }
  else if (mode == 6)
  {
    accelerometer();
  }
}
 

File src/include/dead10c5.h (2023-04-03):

/*!
   @file dead10c5.h
    ____  _____      _    ____    _  ___     ____ ____
   |  _ \| ____|_   / \  |  _ \ _/ |/ _ \ _ / ___| ___|
   | | | |  _| (_) / _ \ | | | (_) | | | (_) |   |___ \
   | |_| | |___ _ / ___ \| |_| |_| | |_| |_| |___ ___) |
   |____/|_____(_)_/   \_\____/(_)_|\___/(_)\____|____/


   Author : @theDevilsVoice https://twitter.com/dead10c5
   Date   : April 3, 2023
   Version: 0.2
*/
#ifndef DEAD10C5_H
#define DEAD10C5

#define VERSION "v0.2 - 03 April 2023 - гопник badge - Путин хуйло"

#include <Arduino.h>        // default library for Arduino
#include <Wire.h>           // used for the I2C communication
#include <SoftwareSerial.h> // used for serial output on the badge

const uint8_t BOTTOM_ROW = PA0; // PB0 on pin2
const uint8_t MIDDLE_ROW = PA1; // PB1 on pin3
const uint8_t TOP_ROW = PB2;    // PB2 on pin5

// MPU6050
const int MPU = 0x68; // MPU6050 I2C address
float AccX, AccY, AccZ;
float GyroX, GyroY, GyroZ;
float accAngleX, accAngleY, gyroAngleX, gyroAngleY, gyroAngleZ;
float roll, pitch, yaw;
float AccErrorX, AccErrorY, GyroErrorX, GyroErrorY, GyroErrorZ;
float elapsedTime, currentTime, previousTime;
int c = 0;

#endif

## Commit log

2022-08-26 moving items to appropriate directories;
    [adidas.kicad_pcb, adidas.kicad_sch]
2022-09-02 resized art and created outline
    [adidas.kicad_pcb]
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2022-09-02 add mpu6050 part (#4)
    * add mpu6050 part
    * add 6050 footprint
    [MPU-6050.step, adidas.kicad_pcb]
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2022-09-04 add a microcontroller (#6)
    * add a microcontroller
    * test ISP header
    * test LED placement
    * test LED placement
    [ATTINY841-SSU.step, adidas.kicad_pcb]
2022-09-06 place chips in schematic (#7)
    * place chips in schematic
    * update schematic
    * update schematic
    [adidas.kicad_pcb, adidas.kicad_sch]
2022-09-07 add SAO header and place LEDs (#8)
    [adidas.kicad_pcb, adidas.kicad_sch]
2022-09-18 move components (#10)
    * move components
    * run freeroute on the PCB
    * run freeroute on the PCB
    * move components
    [adidas.kicad_pcb, adidas.kicad_sch]
2022-10-04 run DRC (#13)
    * run DRC
    * run DRC
    [adidas.kicad_pcb]
2022-10-15 Путин хуйло (#14)
    * Путин хуйло
    * remove zip file
    * update back silkscreen
    * update back silkscreen
    * add BOM for parts ordering
    [adidas.csv, adidas.kicad_pcb, adidas.ods]
2022-10-26 update bom (#16)
    * update bom
    * move resistor to back and update routing
    [adidas.kicad_pcb]
2023-02-18 checkpoint (#17)
    * checkpoint
    * add some file
    * update for KiCAD 7
    [adidas.kicad_pcb, adidas.kicad_sch]
2023-02-18 Cleanup for production (#19)
    * shrink the text on the credits
    * testing new kicad with kibot
    * testing container image
    * update
    * restore kicad 6 files
    * restore kicad 6 files
    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
    [adidas.kicad_pcb, adidas.kicad_sch]
2023-02-18 manage these jank ass libraries (#21)
    * manage these jank ass libraries
    * manage these jank ass libraries
    * manage these jank ass libraries
    [ATTINY841-SSU.step, MPU-6050.step, adidas.kicad_pcb]
2023-02-18 update kibot files (#22)
    * update kibot files
    * when is this going to work
    * generate gerbers
    * generate the BOM
    * remove extra action
    [BOM_PCBWay.xlsx, BomExample-OSpcb.xlsx, Sample_BOM_PCBWay.xlsx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]
2023-02-22 code for the board (#23)
    * code for the board
    * generate 3d front and back images
    * changes after feedback from PCBway
    * make more updates after PCBway feedback
    [adidas.csv, adidas.kicad_pcb, adidas.kicad_sch]
2023-02-22 updates to board (#24)
    * updates to board
    * updates to board
    * tune action
    * board updates
    * update action
    * add markdown action
    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
    [adidas.csv, adidas.kicad_pcb]
2023-02-22 RUN DRC v0.2 (#25)
    * refactor
    * RUN DRC
    * cleanup for v0.2
    * final v0.2
    [ATTINY841-SSU.step, MPU-6050.step, adidas.kicad_pcb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]
2023-02-24 make some changes from PCBway feedback v0.3 (#27)
    * make some changes from PCBway feedback v0.3
    * tune actions
    * add mouser and digikey part numbers
    * run ERC checks
    * run ERC checks
    [adidas.csv, adidas.kicad_pcb, adidas.kicad_sch]
2023-02-24 run ERC checks (#28)
    * kibot testing
    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
    [adidas.csv, adidas.kicad_sch]
2023-02-24 BOM updates (#29)
    * update the battery clip in the BOM
    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
    [adidas.csv, adidas.kicad_pcb, adidas.kicad_sch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]
2023-02-25 more BOM updates (#30)
    [BOM_PCBWay.xlsx, BomExample-OSpcb.xlsx, Sample_BOM_PCBWay.xlsx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]
2023-02-27 update graphics (#31)
    * update graphics
    * change out the LED component
    [adidas.csv, adidas.kicad_pcb, adidas.kicad_sch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]
2023-04-03 testing bootloader burn (#33)
    * testing accelerometer
    * add BF3-1000 switch datasheet
    * add some assembly notes
    * add some LED code
    * update programming instructions
    * update programming instructions
    * burnt bootloader on baords
    * testing board flash
    [ISP_hookup.ods, T-U23W61080A.xlsx]
2023-04-03 testing LED set (#34)
    * testing LED set
    * replace missing serial start
    * cleanup
    [dead10c5.h]
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2023-04-04 update documentation (#39)
    * update documentation
    * update documentation
    * update documentation
    * lint issue
    [BOM_PCBWay.xlsx, BomExample-OSpcb.xlsx, ISP_hookup.ods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]
2023-04-04 replace B3F-100 switch (#40)
    * replace B3F-100 switch
    * update switches, re-add the lanyard hole
    [TL1107BF130WQ.step, adidas.kicad_pcb, adidas.kicad_sch]
2023-04-05 update C++ build (#41)
    * update C++ build
    * remove all traces, move chip and battery holder
    * remove all traces, move chip and battery holder
    [adidas.kicad_pcb]
2023-04-05 testing mpu6050 (#42)
    * testing mpu6050
    * add tiny i2c
    * fix dep5
    * add TInyWireM
    * test platformio
    * move header file
    * move header file
    * add i2c test code
    * disable platformio for now
    [dead10c5.h]
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2023-05-11 random checkpoint (#44)
    * random checkpoint
    * redo routing on PCB
    * refactor a bit
    * more moounting holes
    * tune up reuse
    * tune up reuse
    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
    [ATTINY841-SSU.step, BOM_PCBWay.xlsx, MPU-6050.step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]
2023-05-12 fix refactor (#45)
    * fix refactor
    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
    [ATTINY841-SSU.step, BOM_PCBWay.xlsx, MPU-6050.step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]
2023-05-14 fix reversed battery clip leads (#49)
    * documentation updates
    * documentation updates
    * documentation updates
    * fix battery clip
    [adidas.kicad_pcb, adidas.kicad_sch, battery_clip.step]
2023-05-18 hardware testing (#50)
    * hardware testing
    * hardware testing
    * new hardware test with wire library
    * add some docs on how the new test code is meant to work
    * add docs for flashing the boards
    * add test pin breakouts
    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
    [adidas.kicad_pcb, adidas.kicad_sch]
2023-05-24 clean up the docs (#53)
    * reduce the clutter
    * more cleanup of the docs
    * clean up markdown
    * clean up docs
    [BOM_PCBWay.xlsx, T-U23W61080A.xlsx, adidas.ods]
2023-05-31 updates to the back of the board (#55)
    * updates to the back of the board
    * updates to the back of board
    * update puzzle
    * add svg
    * testing puzzle placement
    * update back of board
    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
    [adidas.kicad_sch]
2023-06-01 fix script to update reference designators on puzzle footprints (#56)
    * fix script to update reference designators on puzzle footprints
    * routing
2023-06-01 flip the battery clip (#57)
    * flip the battery clip
    * update BOM and generate gerbers
    [adidas-B_Cu.gbr, adidas-B_Mask.gbr, adidas-B_Paste.gbr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]
2023-06-12 where are these gerbers coming from (#59)
    [adidas-B_Cu.gbr, adidas-B_Mask.gbr, adidas-B_Paste.gbr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]
2023-07-16 update images (#62)
    * update images
    * update images
    * update images
    [adidas.kicad_sch]
2023-07-21 fix the pin naming in the schematic (#65)
    * fix the pin naming in the schematic
    * update the silkscreen on the back of the board for the pin name changes
    [adidas.kicad_pcb, adidas.kicad_sch]
2023-08-03 what is this crap
    [adidas-B_Cu.gbr, adidas-B_Mask.gbr, adidas-B_Paste.gbr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]
2023-08-04 test badge code and hardware (#69)
    * what is this crap
    * work on finale code
    * clean up the code
    * review current code
    * checkpoint during testing
    * final code, serial test
    * testing some more
    * button and accelerometer working
    * fix markdown lint
    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
    [dead10c5.h, gopnik.ino, hw_test_2.ino]
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
